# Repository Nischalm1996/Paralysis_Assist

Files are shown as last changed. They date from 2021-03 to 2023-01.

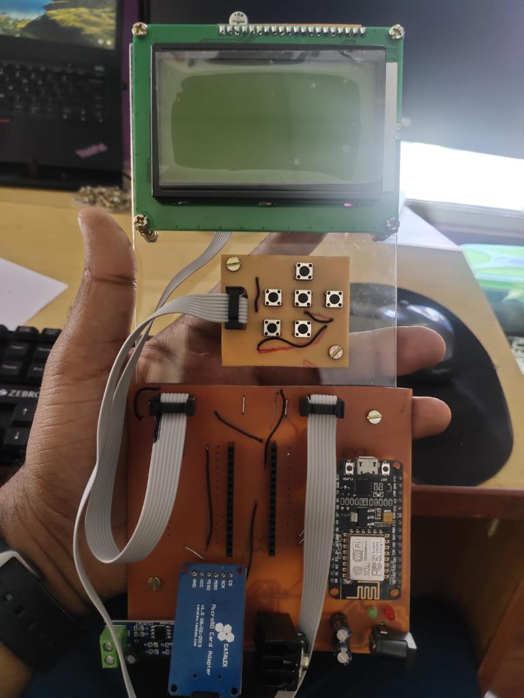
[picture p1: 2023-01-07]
WhatsApp Image 2023-01-07 at 13.04.26.jpg

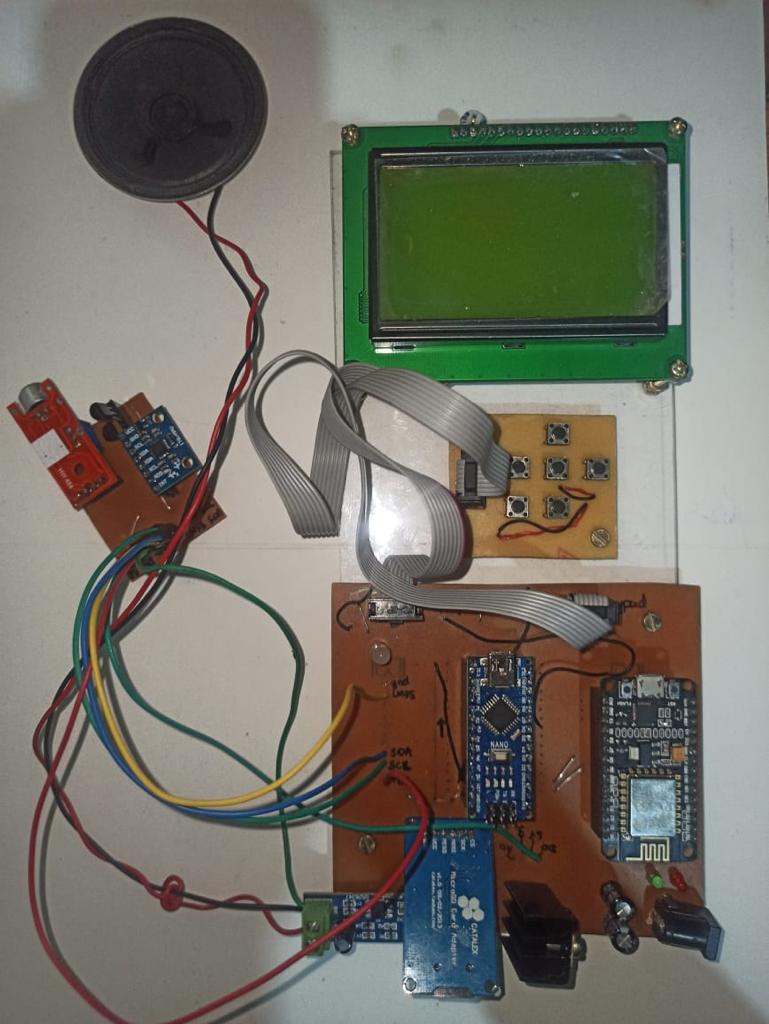
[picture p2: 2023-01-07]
5.jpg

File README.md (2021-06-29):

# Paralysis_Assist

## Pin Connection from Board 
| Pin Name  | Digital Pin |
|---|---|
| CS_SDCARD | D2 |
| SOUND_D0  | D3  *Mic sensor from paralysed person* |
| AUDIO_OUT | D4 *to speaker* |
| MISO | D5 |
| MOSI | D10 |
| OK | D6 |
| LEFT | D7 |
| RIGHT | D9 |
| BACK | D8 |
| RIGHT | D9 |
| CS_DISP | D11 |
| RST | D12 |
| TEMP | A3 |
| RED | A2 |
| GREEN | A1 |
| BLUE | A0 |

### MODULES USED
- DISPLAY 12864 SPI CONNECTOR
- NODE MCU
- MIC SENSOR
- MPU6050 ACCELOROMETER
- SD CARD
- LM35
- NAVIGATION BUTTON
- SOUND OUT----LM386
- RGB LED

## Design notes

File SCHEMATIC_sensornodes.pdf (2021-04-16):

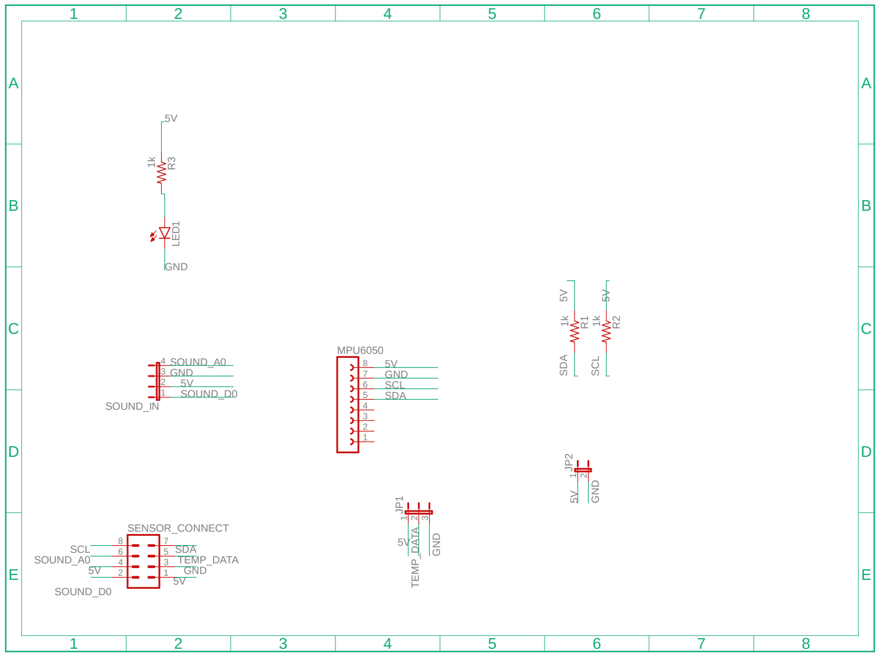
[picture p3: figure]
4 SOUND_IN; 8 MPU6050; 8 7 SENSOR_CONNECT; 2 JP2 LED1 R3; GND; SOUND_A0; SOUND_D0; SDA; SCL; TEMP_DATA TEMP_DATA

4/16/2021 12:42 PM G:\OneDrive\Documents\EAGLE\projects\Paralysis_Assist\Paralysis_Assist\1.PCB_PARALYSIS_ASSIST\pcb_paralysis_sensor_connect\untitled.sch (Sheet: 1/1) ¹k 1k 1k

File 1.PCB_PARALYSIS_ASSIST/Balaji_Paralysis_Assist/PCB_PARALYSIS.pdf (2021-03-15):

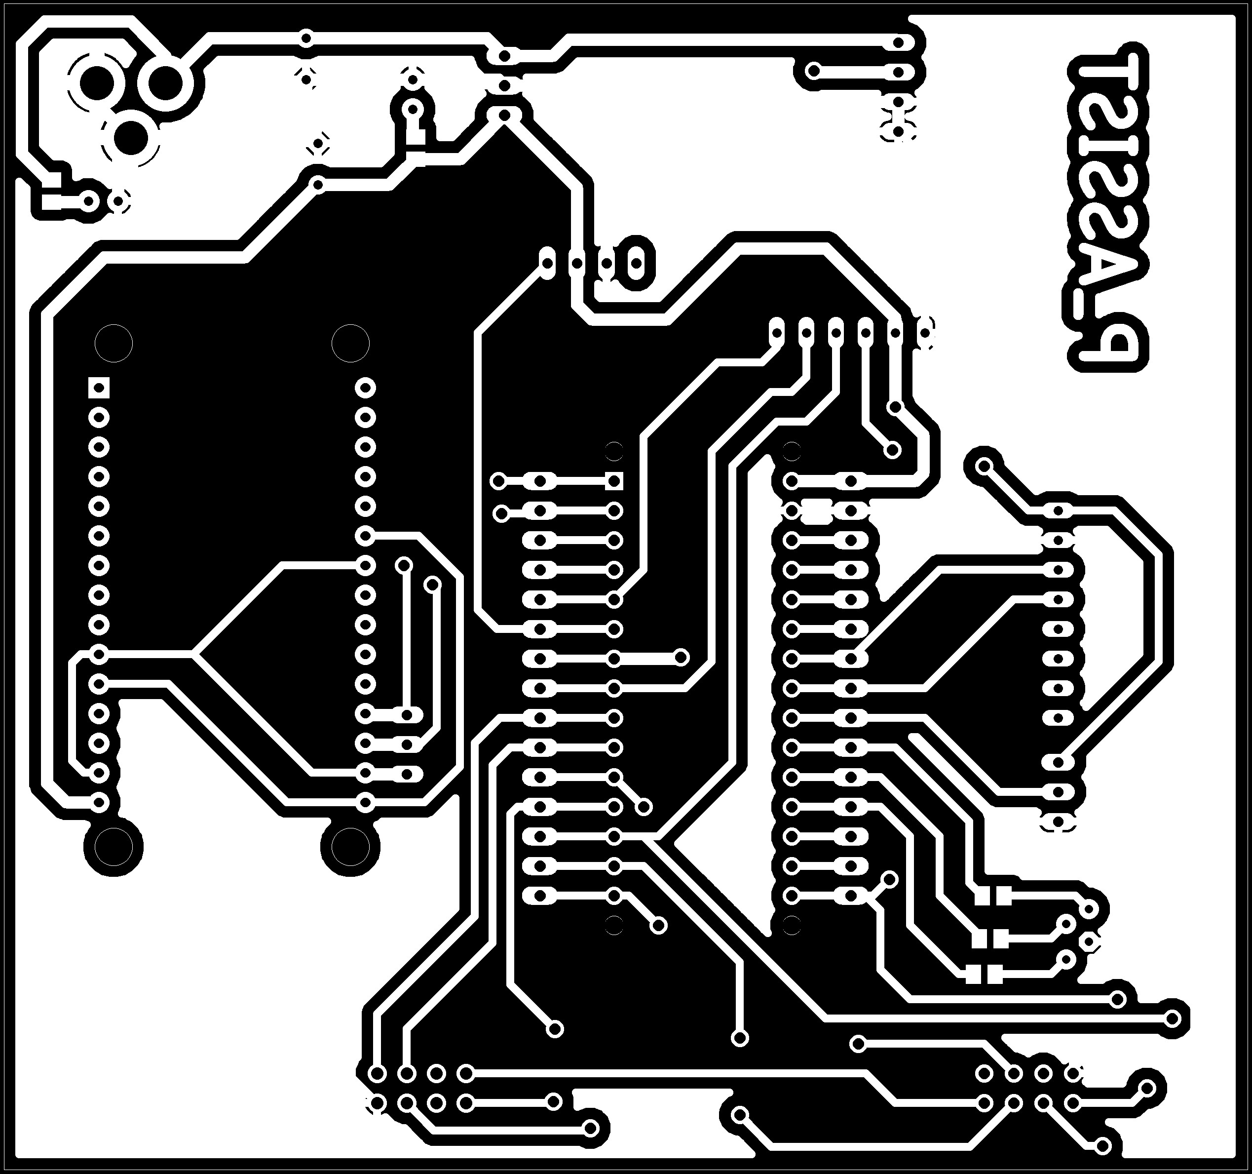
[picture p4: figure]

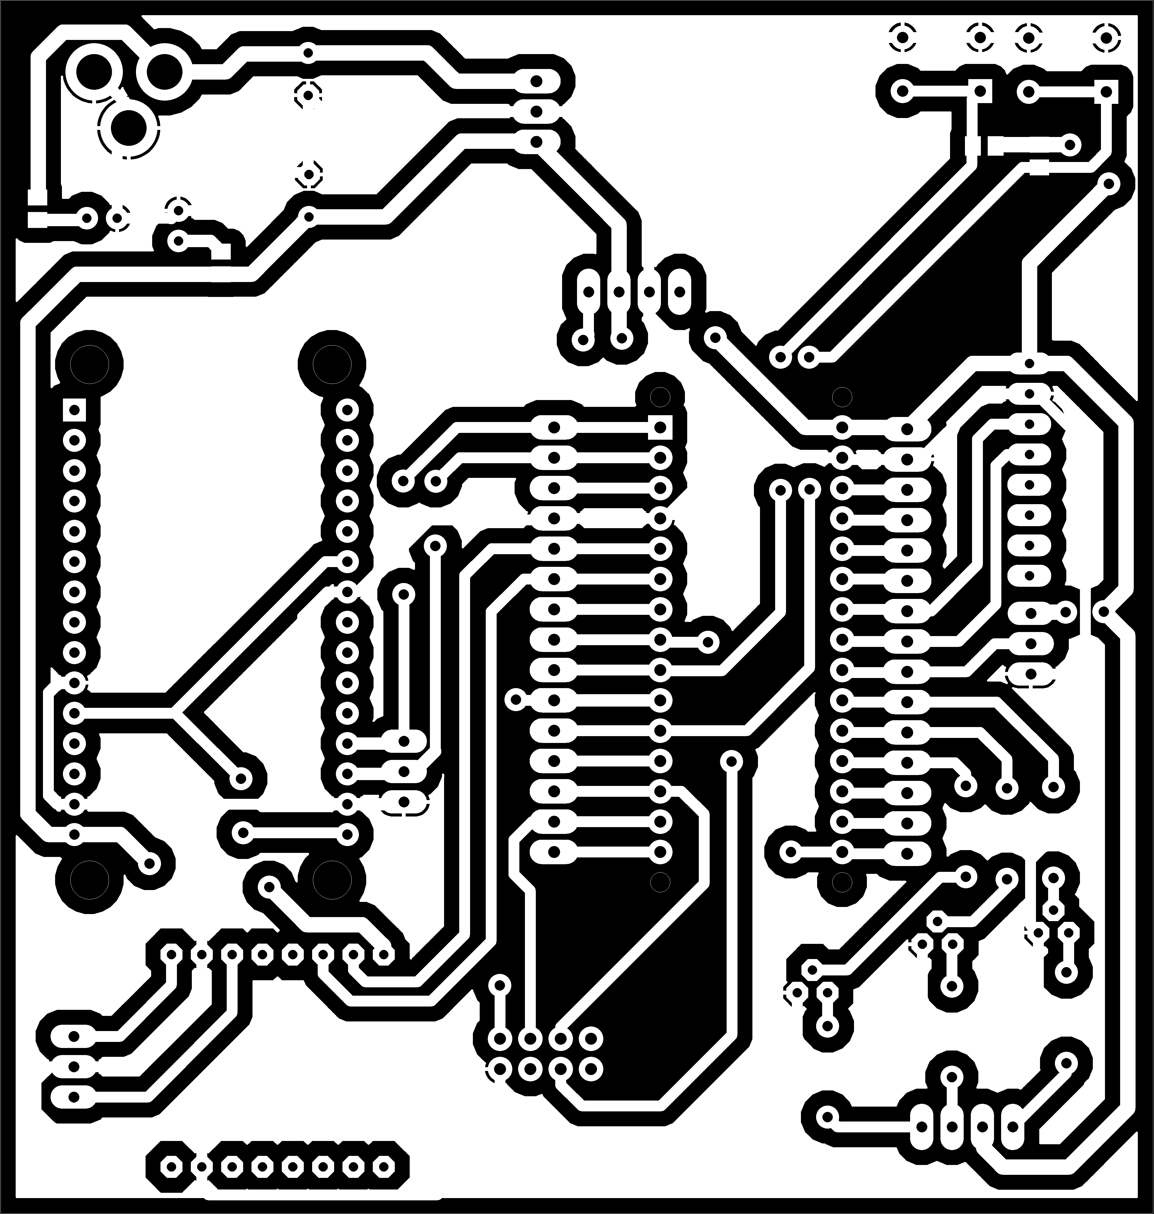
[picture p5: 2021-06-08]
1.PCB_PARALYSIS_ASSIST/paralysis_assist_Version2/pcb.png

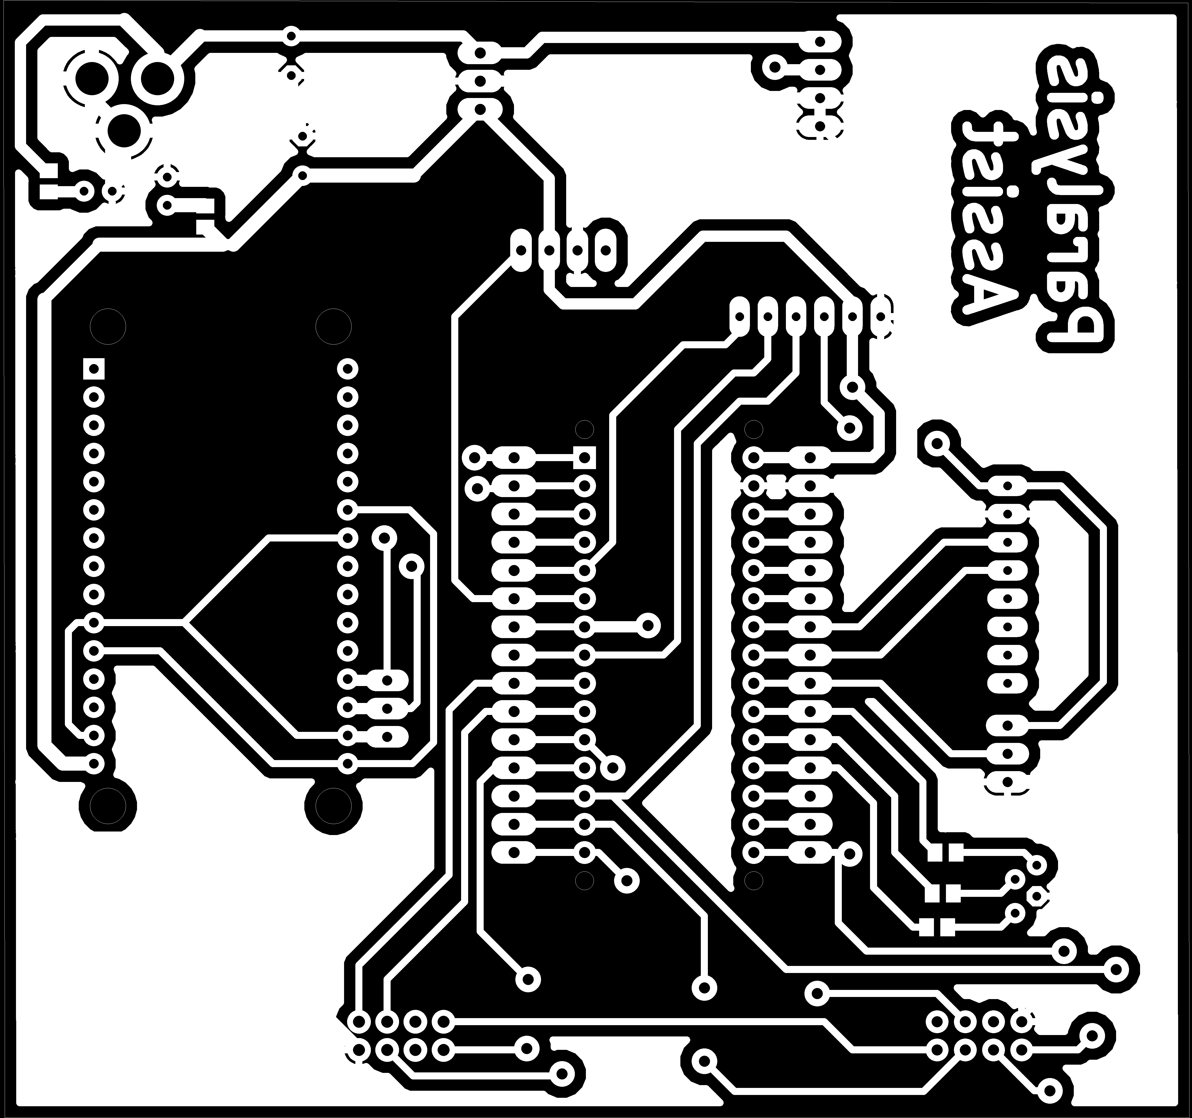
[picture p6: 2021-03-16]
1.PCB_PARALYSIS_ASSIST/Balaji_Paralysis_Assist/bottom_pcb.png

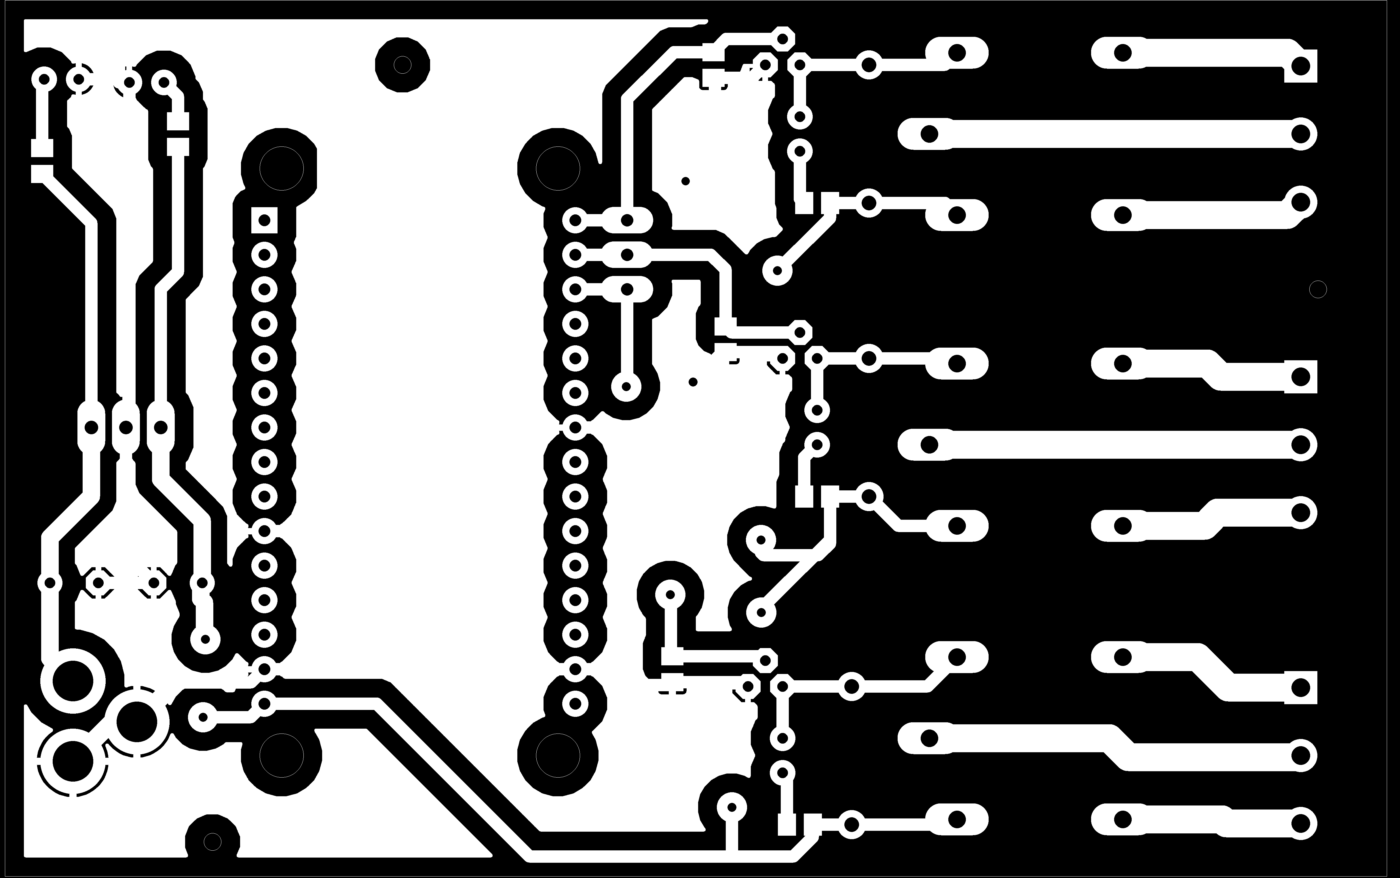
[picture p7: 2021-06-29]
1.PCB_PARALYSIS_ASSIST/node_Mcu_Client/bottom.png

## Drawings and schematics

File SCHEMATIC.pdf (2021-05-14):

4/21/2021 1:17 AM G:\OneDrive\Documents\EAGLE\projects\Paralysis_Assist\Paralysis_Assist\1.PCB_PARALYSIS_ASSIST\Balaji_Paralysis_Assist\Paralysis_Assist_v1.sch (Sheet: 1/1) ¹k

A

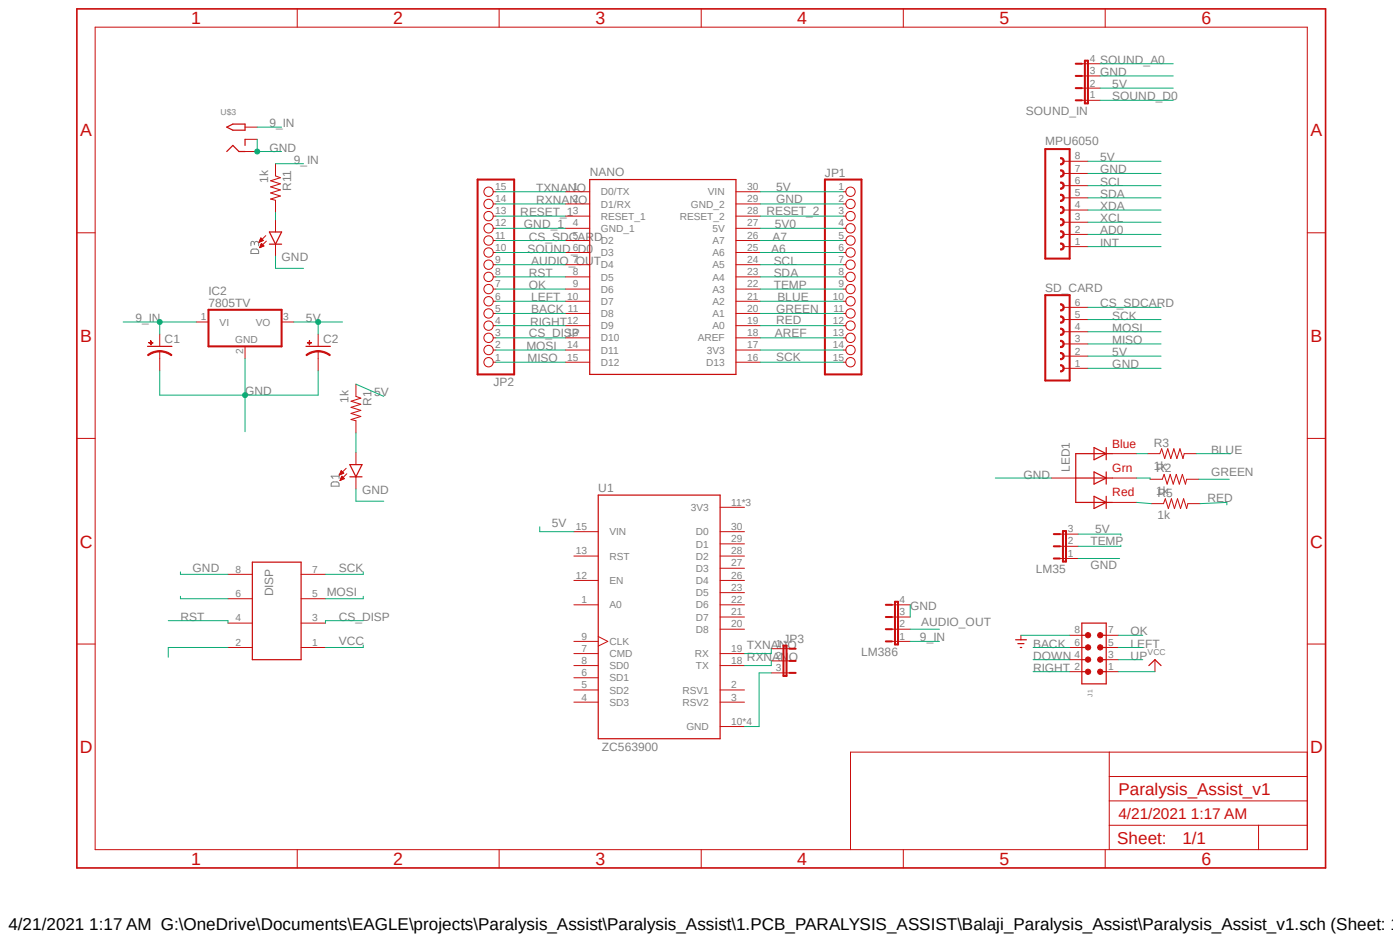
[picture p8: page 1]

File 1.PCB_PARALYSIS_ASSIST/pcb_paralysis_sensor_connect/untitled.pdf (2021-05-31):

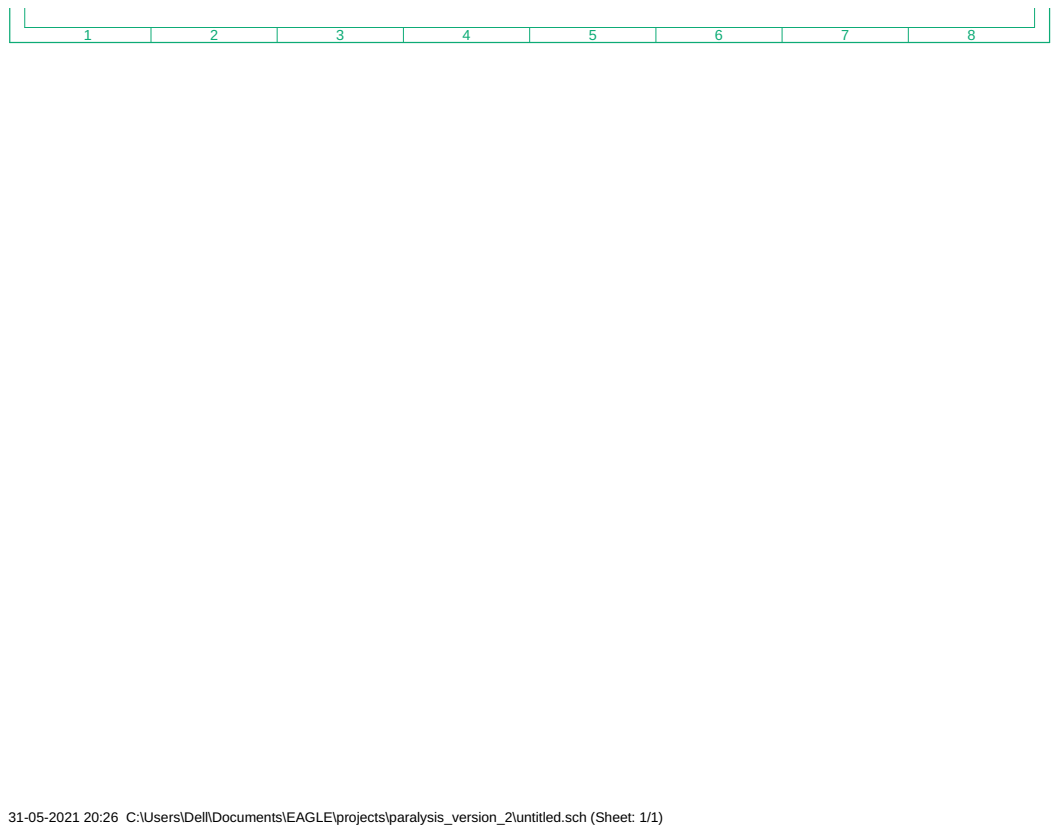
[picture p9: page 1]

31-05-2021 20:26 C:\Users\Dell\Documents\EAGLE\projects\paralysis_version_2\untitled.sch (Sheet: 1/1)

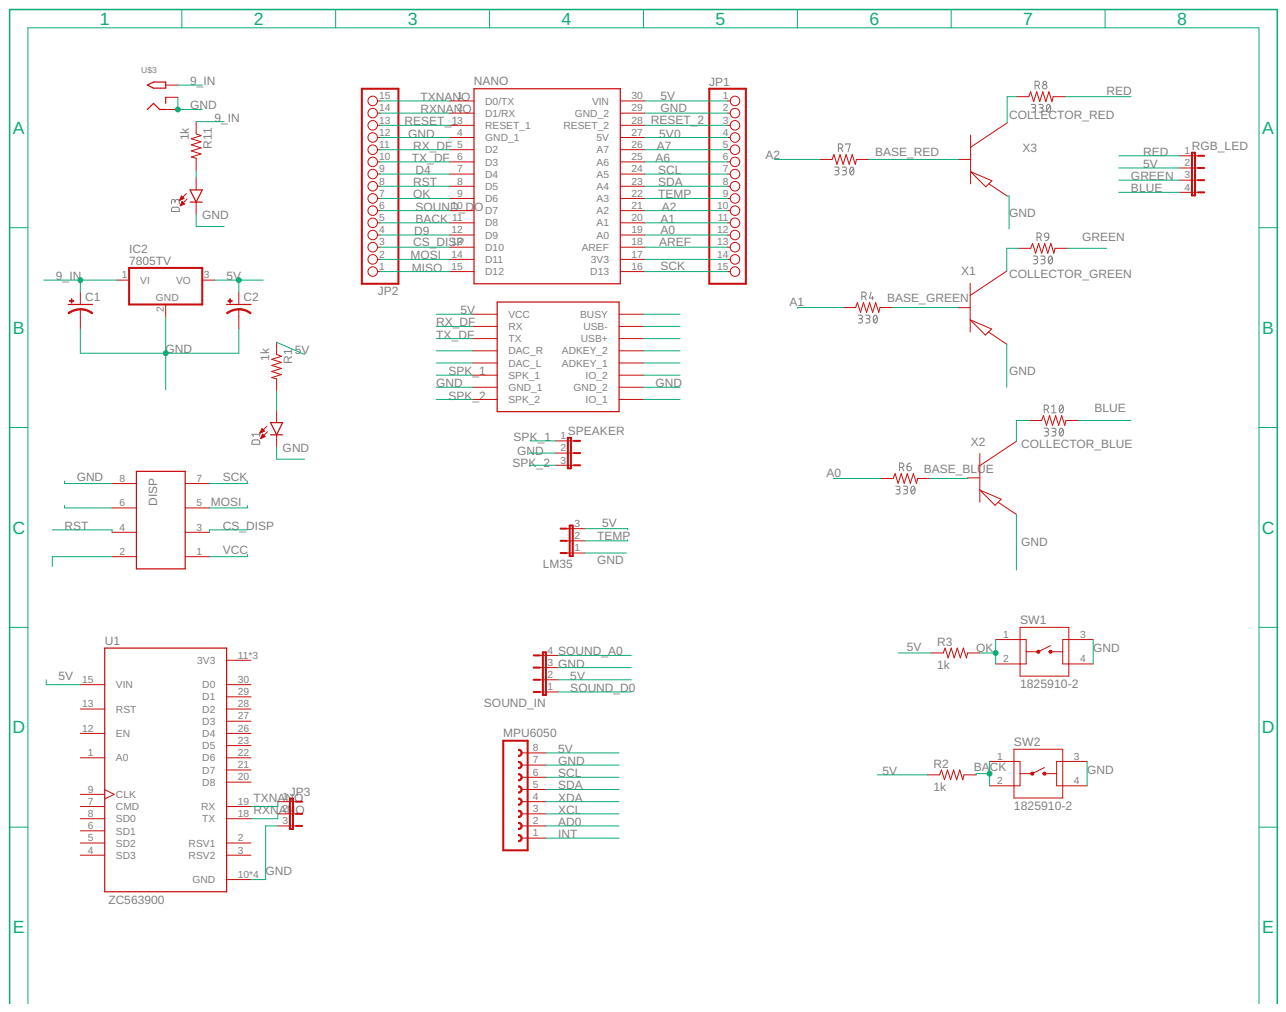
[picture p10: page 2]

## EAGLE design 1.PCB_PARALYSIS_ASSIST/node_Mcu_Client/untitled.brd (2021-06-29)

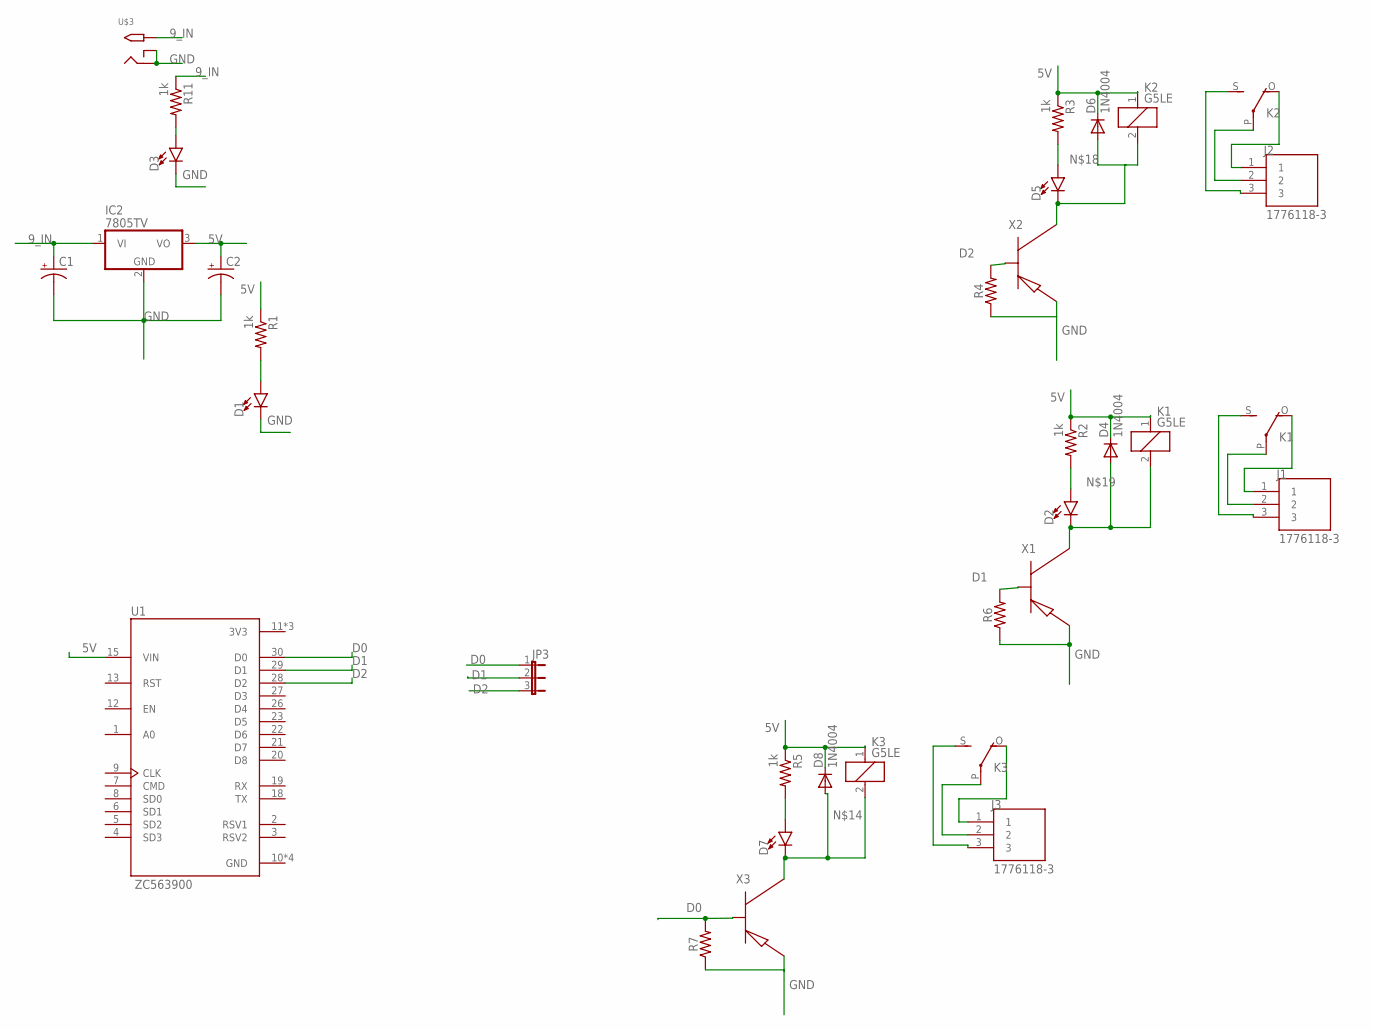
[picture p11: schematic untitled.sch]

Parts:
C1, C2: CPOL-USE3.5-8; E3,5-8
D1, D2, D3, D5, D7: LED3MM; LED_3MM
D4, D6, D8: 1N4004; DO41-10
IC2: 7805TV; TO220V
J1, J2, J3: 1776118-3; TE_1776118-3
JP3: JP2W
K1, K2, K3: G5LE
R1, R2, R3, R5, R11: 1k; M0805
R4, R6, R7: 330; M0805
U1: ZC563900; MODULE_ZC563900
U$3: 2.1MMJACKTHM; PJ-102A
X1, X2, X3: 2N3906; TO92

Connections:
3V3: U1.11 (3V3), U1.16 (3V3), U1.25 (3V3)
5V: C2.+, D4.C, D6.C, D8.C, IC2.3 (VO), K1.1, K2.1, K3.1, R1.1, R2.1, R3.1, R5.1, U1.15 (VIN)
9_IN: C1.+, IC2.1 (VI), R11.1, U$3.TIP
D0: JP3.1, R7.2, U1.30 (D0), X3.2 (B)
D1: JP3.2, R6.2, U1.29 (D1), X1.2 (B)
D2: JP3.3, R4.2, U1.28 (D2), X2.2 (B)
GND: C1.-, C2.-, D1.K (C), D3.K (C), IC2.2 (GND), R4.1, R6.1, R7.1, U1.10 (GND), U1.14 (GND), U1.17 (GND), U1.24 (GND), U$3.RING, U$3.RING_SW, X1.3 (E), X2.3 (E), X3.3 (E)
unnamed: D2.K (C), D4.A, K1.2, X1.1 (C)
unnamed: D3.A, R11.2
unnamed: D1.A, R1.2
unnamed: D7.A, R5.2
unnamed: J1.2, K1.P
unnamed: J1.1, K1.O
unnamed: J1.3, K1.S
unnamed: D5.K (C), D6.A, K2.2, X2.1 (C)
unnamed: J2.2, K2.P
unnamed: J2.1, K2.O
unnamed: J2.3, K2.S
unnamed: D7.K (C), D8.A, K3.2, X3.1 (C)
unnamed: J3.2, K3.P
unnamed: J3.1, K3.O
unnamed: J3.3, K3.S
unnamed: D5.A, R3.2
unnamed: D2.A, R2.2

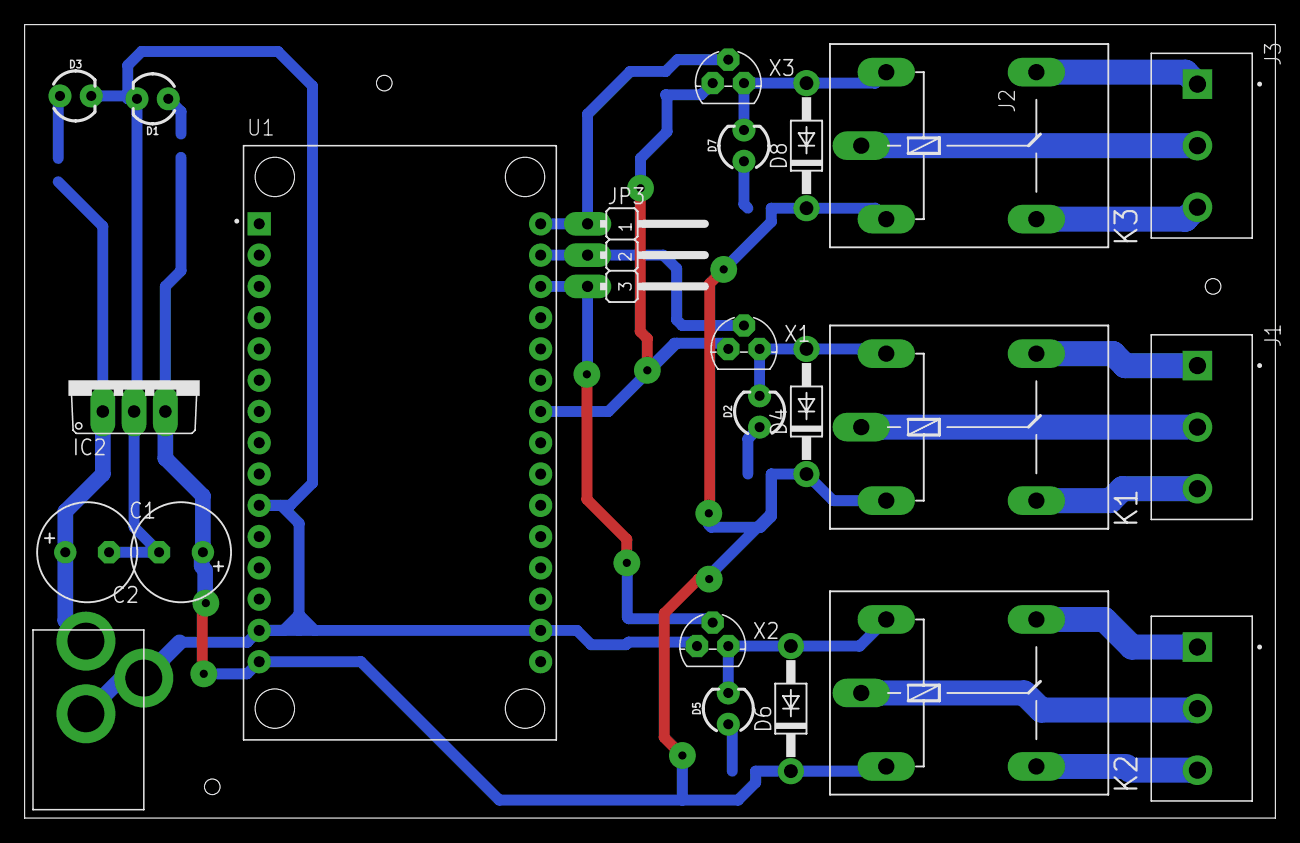
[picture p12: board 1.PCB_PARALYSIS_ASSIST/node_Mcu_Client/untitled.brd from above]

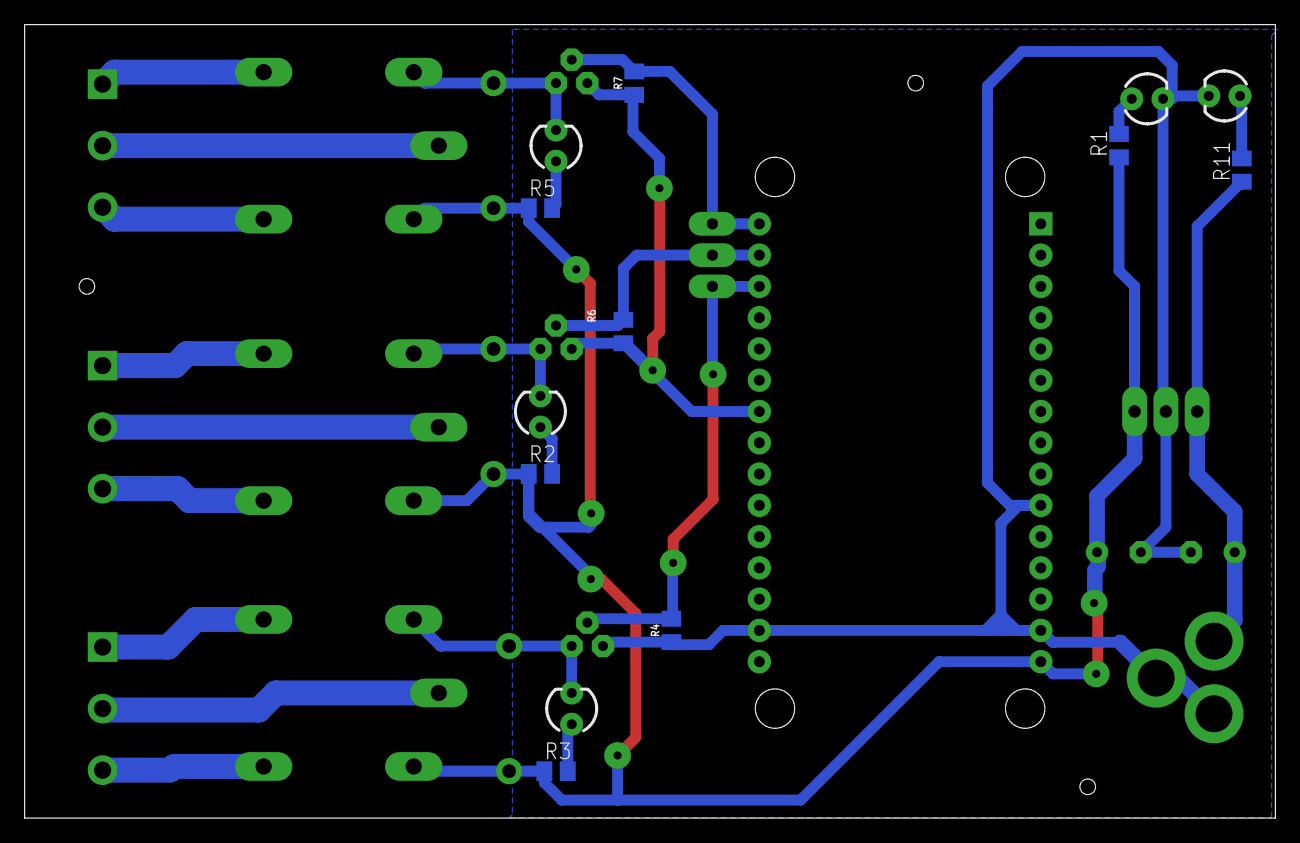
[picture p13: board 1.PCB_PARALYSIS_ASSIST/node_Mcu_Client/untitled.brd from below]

Board: 2 copper layers, 101.6 x 64.4 mm, 31 parts (8 on the bottom side), 24 nets.

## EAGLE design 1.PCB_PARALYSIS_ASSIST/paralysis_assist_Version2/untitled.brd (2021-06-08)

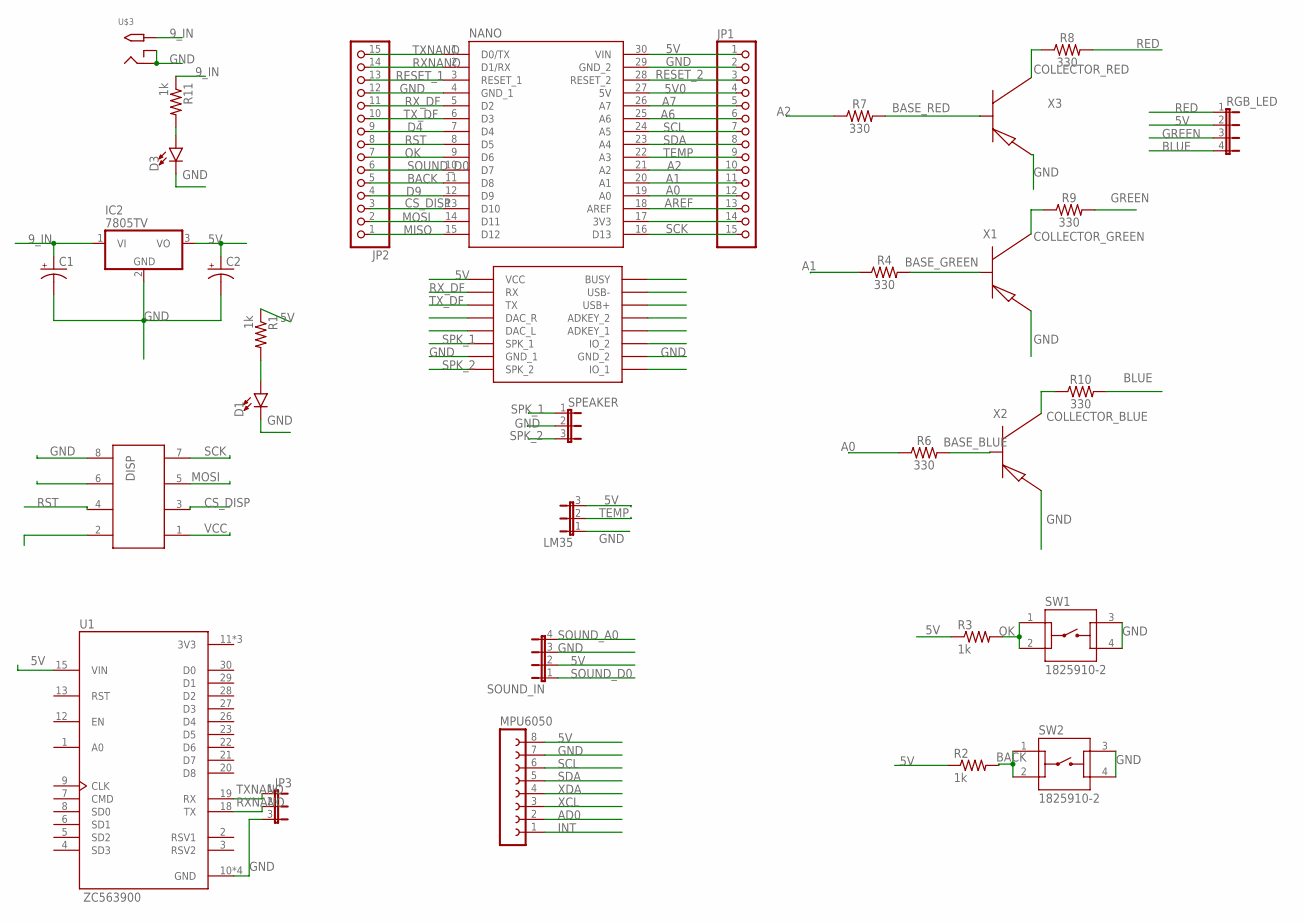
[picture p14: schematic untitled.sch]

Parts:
C1, C2: CPOL-USE3.5-8; E3,5-8
D1, D3: LED3MM; LED_3MM
DISP: 612008235121
IC2: 7805TV; TO220V
JP1, JP2: PINHD-1X15; 1X15
JP3: JP2W
LM35: JP2E; JP2
MPU6050: FE08-1; FE08
NANO: A000005; MODULE_A000005
R1, R2, R3, R11: 1k; M0805
R4, R6, R7, R8, R9, R10: 330; AXIAL-0.3
RGB_LED: JP4E; JP4
SOUND_IN: JP4E; JP4
SPEAKER: JP2E; JP2
SW1, SW2: 1825910-2; TE_1825910-2
U1: ZC563900; MODULE_ZC563900
U$1: DFPLAYER
U$3: 2.1MMJACKTHM; PJ-102A
X1, X2, X3: 2N3906; TO92

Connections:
3V3: U1.11 (3V3), U1.16 (3V3), U1.25 (3V3)
5V: C2.+, IC2.3 (VO), JP1.1, LM35.3, MPU6050.8, NANO.30 (VIN), R1.1, R2.1, R3.1, RGB_LED.2, SOUND_IN.2, U1.15 (VIN), U$1.VCC
5V0: JP1.4, NANO.27 (5V)
9_IN: C1.+, IC2.1 (VI), R11.1, U$3.TIP
A0: JP1.12, NANO.19 (A0), R6.P$1 (1)
A1: JP1.11, NANO.20 (A1), R4.P$1 (1)
A2: JP1.10, NANO.21 (A2), R7.P$1 (1)
A6: JP1.6, NANO.25 (A6)
A7: JP1.5, NANO.26 (A7)
AD0: MPU6050.2
AREF: JP1.13, NANO.18 (AREF)
BACK: JP2.5, NANO.11 (D8), R2.2, SW2.1, SW2.2
BASE_BLUE: R6.P$2 (2), X2.2 (B)
BASE_GREEN: R4.P$2 (2), X1.2 (B)
BASE_RED: R7.P$2 (2), X3.2 (B)
BLUE: R10.P$2 (2), RGB_LED.4
COLLECTOR_BLUE: R10.P$1 (1), X2.1 (C)
COLLECTOR_GREEN: R9.P$1 (1), X1.1 (C)
COLLECTOR_RED: R8.P$1 (1), X3.1 (C)
CS_DISP: DISP.3, JP2.3, NANO.13 (D10)
D4: JP2.9, NANO.7 (D4)
D9: JP2.4, NANO.12 (D9)
GND: C1.-, C2.-, D1.K (C), D3.K (C), DISP.8, IC2.2 (GND), JP1.2, JP2.12, JP3.3, LM35.1, MPU6050.7, NANO.4 (GND_1), NANO.29 (GND_2), SOUND_IN.3, SPEAKER.2, SW1.3, SW1.4, SW2.3, SW2.4, U1.10 (GND), U1.14 (GND), U1.17 (GND), U1.24 (GND), U$1.GND_1, U$1.GND_2, U$3.RING, U$3.RING_SW, X1.3 (E), X2.3 (E), X3.3 (E)
GREEN: R9.P$2 (2), RGB_LED.3
INT: MPU6050.1
MISO: JP2.1, NANO.15 (D12)
MOSI: DISP.5, JP2.2, NANO.14 (D11)
unnamed: D3.A, R11.2
unnamed: D1.A, R1.2
unnamed: JP1.14, NANO.17 (3V3)
OK: JP2.7, NANO.9 (D6), R3.2, SW1.1, SW1.2
RED: R8.P$2 (2), RGB_LED.1
RESET_1: JP2.13, NANO.3 (RESET_1)
RESET_2: JP1.3, NANO.28 (RESET_2)
RST: DISP.4, JP2.8, NANO.8 (D5)
RXNANO: JP2.14, JP3.2, NANO.2 (D1/RX), U1.18 (TX)
RX_DF: JP2.11, NANO.5 (D2), U$1.RX
SCK: DISP.7, JP1.15, NANO.16 (D13)
SCL: JP1.7, MPU6050.6, NANO.24 (A5)
SDA: JP1.8, MPU6050.5, NANO.23 (A4)
SOUND_A0: SOUND_IN.4
SOUND_D0: JP2.6, NANO.10 (D7), SOUND_IN.1
SPK_1: SPEAKER.1, U$1.SPK1 (SPK_1)
SPK_2: SPEAKER.3, U$1.SPK2 (SPK_2)
TEMP: JP1.9, LM35.2, NANO.22 (A3)
TXNANO: JP2.15, JP3.1, NANO.1 (D0/TX), U1.19 (RX)
TX_DF: JP2.10, NANO.6 (D3), U$1.TX
VCC: DISP.1
XCL: MPU6050.3
XDA: MPU6050.4

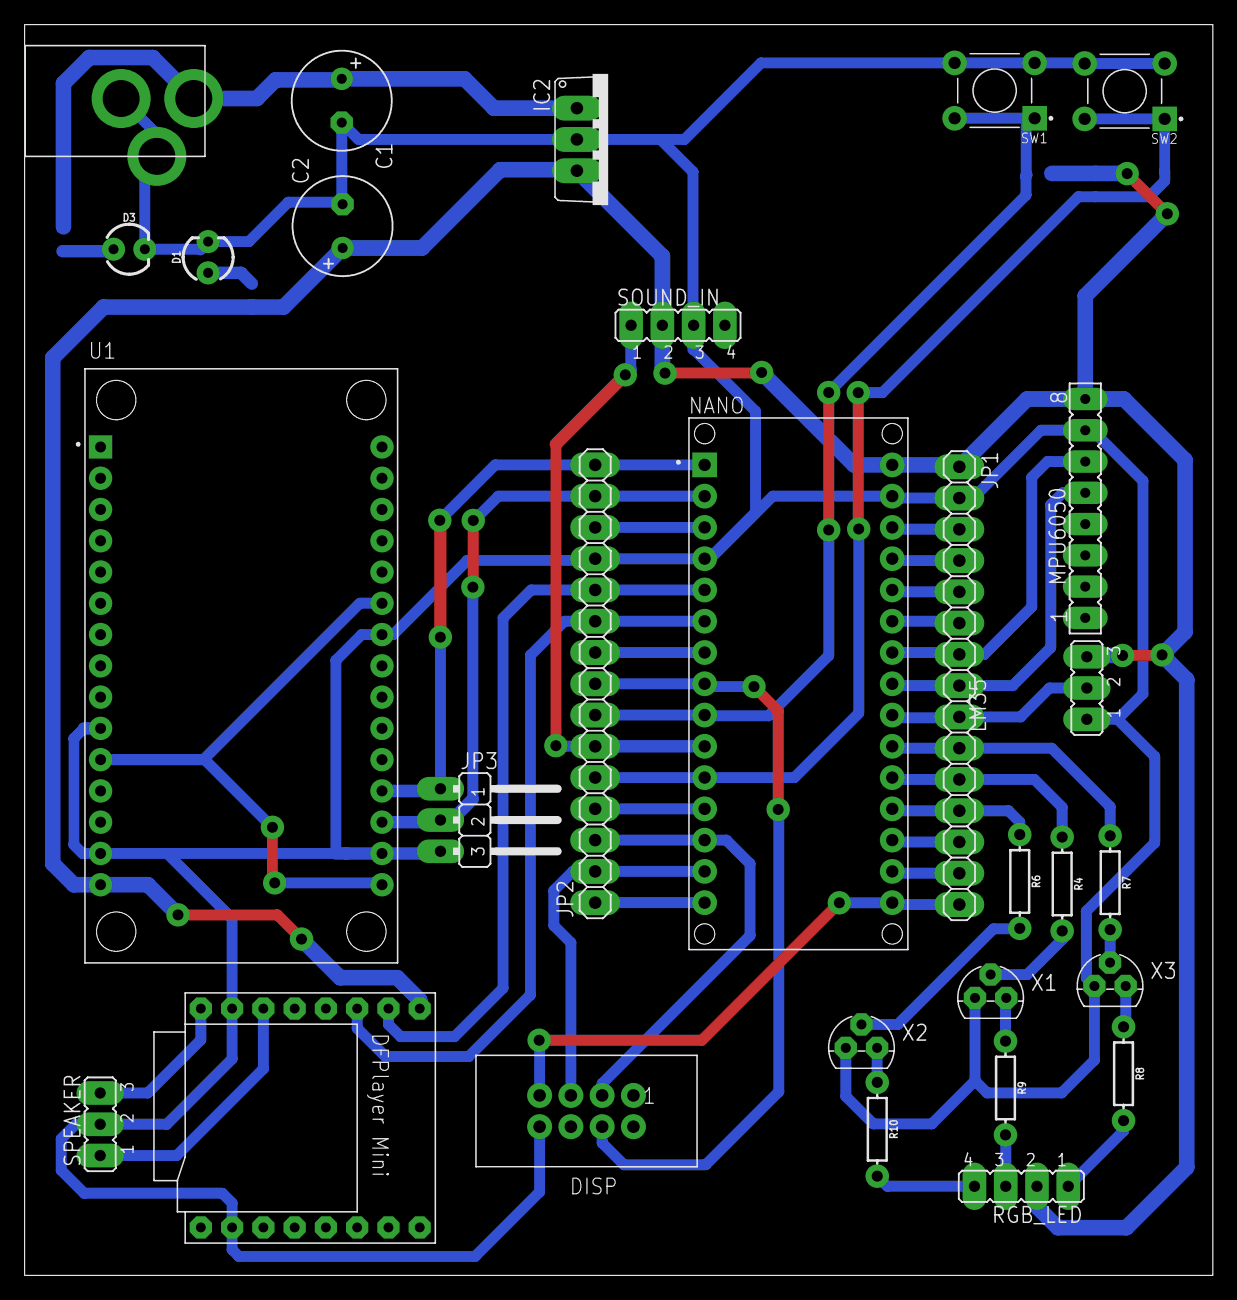
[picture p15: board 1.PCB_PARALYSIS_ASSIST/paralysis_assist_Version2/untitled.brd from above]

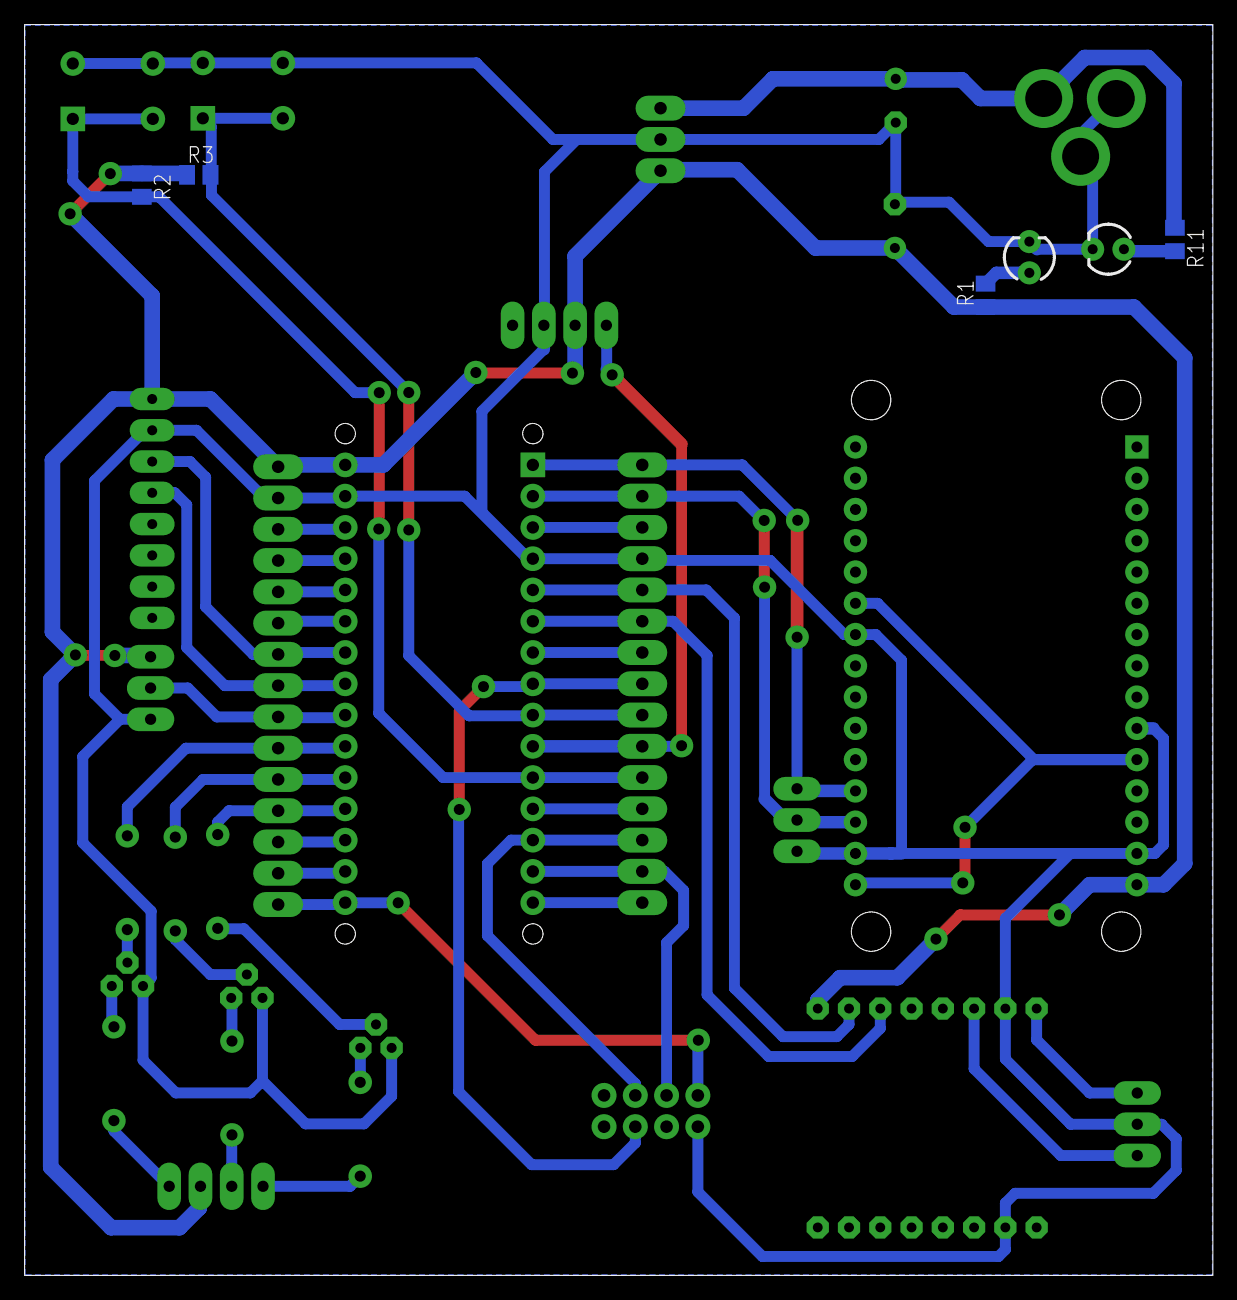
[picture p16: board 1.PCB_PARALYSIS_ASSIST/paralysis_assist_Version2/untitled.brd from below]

Board: 2 copper layers, 96.5 x 101.6 mm, 33 parts (4 on the bottom side), 44 nets.

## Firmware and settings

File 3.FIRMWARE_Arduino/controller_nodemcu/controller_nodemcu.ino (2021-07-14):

/****************************************************************************************************************************************************
    TITLE: ESP-NOW Getting Started Examples

    By Frenoy Osburn
    YouTube Video: https://youtu.be/_cNAsTB5JpM
 ****************************************************************************************************************************************************/

/********************************************************************************************************************
   Please make sure that you install the board support package for the ESP8266 boards.
   You will need to add the following URL to your Arduino preferences.
   Boards Manager URL: http://arduino.esp8266.com/stable/package_esp8266com_index.json
********************************************************************************************************************/

/********************************************************************************************************************
   Board Settings:
   Board: "WeMos D1 R1 or Mini"
   Upload Speed: "921600"
   CPU Frequency: "80MHz"
   Flash Size: "4MB (FS:@MB OTA:~1019KB)"
   Debug Port: "Disabled"
   Debug Level: "None"
   VTables: "Flash"
   IwIP Variant: "v2 Lower Memory"
   Exception: "Legacy (new can return nullptr)"
   Erase Flash: "Only Sketch"
   SSL Support: "All SSL ciphers (most compatible)"
   COM Port: Depends *On Your System
*********************************************************************************************************************/
#include<ESP8266WiFi.h>
#include<espnow.h>
#include"callBot.h"


#define MY_NAME         "MASTER_NODE"
#define MY_ROLE         ESP_NOW_ROLE_CONTROLLER         // set the role of this device: CONTROLLER, SLAVE, COMBO
#define RECEIVER_ROLE   ESP_NOW_ROLE_SLAVE              // set the role of the receiver
#define WIFI_CHANNEL    1
uint8_t receiverAddress[] = {0x48, 0x3F, 0xDA, 0xA3, 0x80, 0x76};   // please update this with the MAC address of the receiver
callBot wtsMsg;

struct __attribute__((packed)) dataPacket {
  boolean light1;
  boolean light2;
  boolean light3;
  boolean fall;
};
static dataPacket packet;

char c = 0;
String dataIn = "";
void transmissionComplete(uint8_t *receiver_mac, uint8_t transmissionStatus) {
  if (transmissionStatus == 0) {
    Serial.println("Data sent successfully");
  } else {
    Serial.print("Error code: ");
    Serial.println(transmissionStatus);
  }
}
void serialOp()
{
  while (Serial.available() > 0)
  {
    c = Serial.read();
    if (c == 'X') {
      //dataIn = dataIn + c;
      break;
    }
    else if (c != '\n')   {
      dataIn = dataIn + c;
    }
    // Serial.print("dataIn:"); Serial.println(dataIn);

  }
  if (c == 'X')
  {
    //Serial.println("parse");
    //Serial.println(dataIn);
    parse_the_data();
  }
}
void parse_the_data()
{
  int indexofS = dataIn.indexOf("*");
  int indexofx = dataIn.indexOf("X");

  String dat = dataIn.substring (indexofS + 1 , indexofx);
  //Serial.print("Dat:"); Serial.println(dat);

  if (dat == "1")
  {
    packet.light1 = !packet.light1;
    esp_now_send(receiverAddress, (uint8_t *) &packet, sizeof(packet));

  }
  if (dat == "2")
  {
    packet.light2 = !packet.light2;
    esp_now_send(receiverAddress, (uint8_t *) &packet, sizeof(packet));

  }
  if (dat == "3")
  {
    packet.light3 = !packet.light3;
    esp_now_send(receiverAddress, (uint8_t *) &packet, sizeof(packet));

  }
  if (dat == "4")
  {
    packet.fall = true;
    Serial.println("fall detected");
    esp_now_deinit();
    wtsMsg.begin();
    wtsMsg.sendWhatsappMessage();
    WiFi.mode(WIFI_STA);
    WiFi.disconnect();        // we do not want to connect to a WiFi network
    if (esp_now_init() != 0) {
      Serial.println("ESP-NOW initialization failed");
      return;

    }
    esp_now_set_self_role(MY_ROLE);
    esp_now_register_send_cb(transmissionComplete);   // this function will get called once all data is sent
    esp_now_add_peer(receiverAddress, RECEIVER_ROLE, WIFI_CHANNEL, NULL, 0);
    esp_now_send(receiverAddress, (uint8_t *) &packet, sizeof(packet));

    //send data to client
  }
  packet.fall = false;
  esp_now_send(receiverAddress, (uint8_t *) &packet, sizeof(packet));
  c = 0;
  dataIn = "";
}
void setup() {
  Serial.begin(9600);     // initialize serial port
  WiFi.mode(WIFI_STA);
  WiFi.disconnect();        // we do not want to connect to a WiFi network
  //wtsMsg.begin();

  if (esp_now_init() != 0) {
    Serial.println("ESP-NOW initialization failed");
    return;

  }

  esp_now_set_self_role(MY_ROLE);
  esp_now_register_send_cb(transmissionComplete);   // this function will get called once all data is sent
  esp_now_add_peer(receiverAddress, RECEIVER_ROLE, WIFI_CHANNEL, NULL, 0);

  packet.light1 = false;
  packet.light2 = false;
  packet.light3 = false;
  packet.fall = false;
  Serial.println("Initialized.");
}

void loop() {
  serialOp();
  delay(3000);
}

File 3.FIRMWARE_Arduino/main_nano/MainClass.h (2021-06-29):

/* This library is for Display memu creation along with input */
#ifndef DISPLAY_ST7920
#define DISPLAY_ST7920

//#include <Arduino.h>
#include <U8g2lib.h>
#include "LM393.h"
#include "mpu6050_imu.h"
//#include "SerialCOM.h"
#include "LM35.h"
#include "DFPlayer.h"

#include <SPI.h>


#define SPEAK_STATE       1   // if selected is speak
#define SWITCH_STATE      2   // if selected is switch
#define NURSE_STATE       3   // if selected is speak->Nurse
#define WATER_STATE       4   // if selected is speak->Water
#define MEDICIN_STATE     5  // if selected is speak->Medicin
#define FOOD_STATE        6   // if selected is speak->Food
#define SWITCH1_STATE     7   // if selected is Switch->Fan
#define SWITCH2_STATE     8   // if selected is Switch->Light
#define SWITCH3_STATE     9   // if selected is Switch->Light

#define buttonPin             8  // BACK button
#define buttonConformation    6  // OK button
#define soundPin              7  // Sound sensor Pin

//const char* COMMAND = "CLICK TO...";  // Displaying on main menu screen
//const char*  REQ_COMMAND = "REQUESTING..."; // displaying on requesting speak service menu
float temparature = 0;
//char buff[8] = "27.13";
boolean fallDetected = false;
byte cnt = 0;

/* U8G2 initiation */
//U8G2_ST7920_192X32_F_8080 u8g2(U8G2_R0, 8, 9, 10, 11, 4, 5, 6, 7, /*enable=*/ 18, /*cs=*/ U8X8_PIN_NONE, /*dc=*/ 17, /*reset=*/ U8X8_PIN_NONE);
//U8G2_ST7920_192X32_F_SW_SPI u8g2(U8G2_R0, /* clock=*/ 18 /* A4 */ , /* data=*/ 16 /* A2 */, /* CS=*/ 17 /* A3 */, /* reset=*/ U8X8_PIN_NONE);
//U8G2_ST7920_128X64_F_8080 u8g2(U8G2_R0, 8, 9, 10, 11, 4, 5, 6, 7, /*enable=*/ 18 /* A4 */, /*cs=*/ U8X8_PIN_NONE, /*dc/rs=*/ 17 /* A3 */, /*reset=*/ 15 /* A1 */);  // Remember to set R/W to 0
//U8G2_ST7920_128X64_F_SW_SPI u8g2(U8G2_R0, /* clock=*/ 18 /* A4 */ , /* data=*/ 16 /* A2 */, /* CS=*/ 17 /* A3 */, /* reset=*/ U8X8_PIN_NONE);
//U8G2_ST7920_128X64_F_SW_SPI u8g2(U8G2_R0, /* clock=*/ 13, /* data=*/ 11, /* CS=*/ 10, /* reset=*/ 8);
//U8G2_ST7920_128X64_F_SW_SPI u8g2(U8G2_R0, /* clock=*/ 14, /* data=*/ 13, /* CS=*/ 15, /* reset=*/ 16); // Feather HUZZAH ESP8266, E=clock=14, RW=data=13, RS=CS
U8G2_ST7920_128X64_F_HW_SPI u8g2(U8G2_R2, /* CS=*/ 10, /* reset=*/ 5);
//U8G2_ST7920_128X64_F_HW_SPI u8g2(U8G2_R0, /* CS=*/ 15, /* reset=*/ 16); // Feather HUZZAH ESP8266, E=clock=14, RW=data=13, RS=CS
//U8G2_ST7920_128X64_F_SW_SPI u8g2(U8G2_R2, /* clock=*/ 13, /* data=*/ 10, /* CS=*/ 11, /* reset=*/ 12);
//U8G2_ST7920_128X64_F_SW_SPI u8g2(U8G2_R2, /* clock=*/ 13, /* data=*/ 11, /* CS=*/ 10, /* reset=*/ 5);

LM393 ObjSound(soundPin); // Create Sound sensor object
MPU6050 ObjImu;   // Object for MPU6050, for fall detection */
//comComm ObjCOM;   // Serial Communication
lm35  ObjLM35(A3);
DFPlayer music;
/* Class for Display Memu */
boolean led_red = false;
boolean led_blue = false;
boolean led_green = false;
class MainClass
{

  public:

    byte Speak_Swt = 0;  // gives seleted speak =1, switch = 2
    byte Speak_Cnt = 0;  // keep track of speak commands
    byte Switch_Cnt = 0; // keep track of switch commands
    byte StateChanged = 0; // gives latest state changed
    bool gotServiceFlag = 0; //gives the ressults of service placed or not
    bool debounce1 = true; // button confirmation for service placed
    bool soundDetected = true; // flag to avoid multiple sound detection
    //const char command_disp[2][10] PROGMEM = {"SPEAK", "SWITCHES"}; // Display on main memu options
    //const char switch_ctrl[3][17] PROGMEM = {"TOGGLE FAN SWT", "TOGGLE LIGHT_1", " TOGGLE LIGHT_2"}; // Toggle switch controls
    //const char speak_ctrl[4][10] PROGMEM = {"NURSE" , "WATER", "MEDICIN", "FOOD"}; //Display on speak service request screen
    byte Cnt = 0;

    void Init()
    {
      ObjSound.Init();    // Begin LM393(soundSensor)
      ObjImu.beginMPU();  // Begin MPU
      //    ObjCOM.Init();      // Begin NODEMCU Serial
      pinMode(buttonConformation, INPUT);
      //  pinMode(buttonPin, INPUT);  // sound pin  // has to change
      u8g2.begin(); //
      //Serial.begin(9600); // just for debug
      Serial.begin(9600);
      Serial.println(F("Begin"));
      music.beginSetup();
      music.DFPlay(10);

    }

    /* Run Menu */
    void runMenu()
    {
      u8g2.clearBuffer();          // clear the internal memory
      //u8g2.setFont(u8g2_font_profont10_tf); // choose a suitable font
      u8g2.setFont(u8g2_font_ncenB08_tr); // choose a suitable font
      u8g2.setFontDirection(0);
      getSpeak_SwitchCmd();
    }
    void display_delay(int period)
    {

      unsigned long time_now = millis();

      /*********** This block will prints temperture ************/
      temparature = ObjLM35.getTempCelcius();
      u8g2.setCursor(5, 64);
      u8g2.print(F("T:"));
      if (temparature > 0 )
      {
        u8g2.setCursor(15, 64);
        //dtostrf(temparature, 4, 2, buff);
        // u8g2.print(F("27.34"));
        u8g2.print(temparature);
      }

      // u8g2.setCursor(64, 64);
      // u8g2.print(fallVal);

      u8g2.sendBuffer();

      /***********************************************************/

      while (millis() < (time_now + period)) {
        //wait approx. [period] ms

        /* This block is for fall detection */
        ObjImu.detectFall(&fallDetected);
        if (fallDetected == true)
        { // Problem causing at here
          Fall_Detected();    // Uncommenting this cause flikeeing problem
          fallDetected = false;
          //break;
        }

        if (ObjSound.readSoundSens() == 0 && soundDetected == false) //Read Sound Sensor state outputs 1 when sound detected
        {
          soundDetected = true;
          //Serial.println("Sound detected");
          if (Speak_Cnt == 0 && Switch_Cnt == 0) // when no switch/speak commands are selected
          {
            switch (Speak_Swt)
            {
              //Serial.println(Speak_Swt);
              case 1: StateChanged = SPEAK_STATE;
                break;
              case 2: StateChanged = SWITCH_STATE;
                break;
              default: ;// do nothing
            }
          }

          // Speak controls selection
          switch (Speak_Cnt)
          {
            case 1: StateChanged = NURSE_STATE;
              break;
            case 2: StateChanged = WATER_STATE;
              break;
            case 3: StateChanged = MEDICIN_STATE;
              break;
            case 4: StateChanged = FOOD_STATE;
              break;
            default: ;// do nothing
          }

          // Switch controls selection
          switch (Switch_Cnt)
          {
            case 1: StateChanged = SWITCH1_STATE;
              break;
            case 2: StateChanged = SWITCH2_STATE;
              break;
            case 3: StateChanged = SWITCH3_STATE;
              break;
            default: ;// do nothing
          }

          //break; // break while loop is sound detected
        }
      }// end of while
    }
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

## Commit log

2021-03-16 added image
    [Paralysis_Assist_v1.brd]
2021-03-25 added Schematic
2021-04-04 pcb_sensor_connect
    connecting the sensor in one pcb
    [untitled.brd, untitled.sch]
2021-04-04 small board
    [untitled.brd, untitled.sch]
2021-04-16 added schematics
2021-05-14 pcb changes
    [Paralysis_Assist_v1.brd, Paralysis_Assist_v1.sch]
2021-05-31 paralysis_version2 added pcb design
    design added
    [untitled.brd, untitled.sch]
2021-05-31 updated version_2 layout
    [untitled.brd, untitled.sch]
2021-06-02 corrections to the pcb
    [untitled.brd]
2021-06-02 added pcb
2021-06-08 image file edited for print
    [untitled.brd]
2021-06-16 added Arduino Code
2021-06-20 Final Working with Audio issue fixed!
    [MainClass.h]
2021-06-29 nodemcu pcb reciever added
    [untitled.brd, untitled.sch]
2021-06-29 RGB led analog pin numbers added
2021-06-29 updated led functionality
2021-06-29 updated pic of pcb
    [untitled.brd]

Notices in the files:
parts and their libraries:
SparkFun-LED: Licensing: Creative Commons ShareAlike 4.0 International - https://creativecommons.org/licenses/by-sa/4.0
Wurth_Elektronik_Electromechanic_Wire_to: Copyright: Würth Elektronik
